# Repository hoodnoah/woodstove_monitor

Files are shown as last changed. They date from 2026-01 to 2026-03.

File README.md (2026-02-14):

# Woodstove Monitor

A Rust-based temperature monitoring system for woodstoves using an Arduino Nano ESP32 and a MAX31855 thermocouple sensor. The device reads temperature data and publishes it to MQTT for remote monitoring.

## Features

- **Temperature Monitoring**: Reads thermocouple data via MAX31855 SPI sensor
- **WiFi Connectivity**: Connects to WiFi networks for remote access
- **MQTT Publishing**: Publishes temperature readings and stove state to an MQTT broker
- **State Machine**: Tracks woodstove burn state based on temperature readings
- **Low Power**: Optimized for minimal resource usage on embedded systems

## Hardware

- Arduino Nano ESP32 (ESP32-S3)
- MAX31855 Thermocouple Amplifier (SPI interface)
- Status LED (GPIO8)
- WiFi antenna

## Project Structure

- `monitor/`: Main ESP32 application (firmware)
  - `main.rs`: Entry point, hardware setup, main loop
  - `mqtt.rs`: MQTT client and publishing logic
  - `wifi.rs`: WiFi connectivity
- `woodstove_lib/`: Shared library with core logic
  - `state_machine.rs`: Stove state tracking
  - `sensor.rs`: Sensor abstractions
  - `temperature.rs`: Temperature value types

## Setup

### Prerequisites

See [SETUP.md](SETUP.md) for detailed platform-specific installation instructions.

**Quick setup:**

1. Install system dependencies (cmake, ninja, LLVM, Python 3.12, etc. - see SETUP.md)
2. Set required environment variables (see SETUP.md)
3. Install ESP tooling:
   ```bash
   just check-deps  # Verify dependencies
   just setup       # Install ESP tools (one-time)
   source ~/export-esp.sh  # Load ESP environment
   ```

### Configuration

Set environment variables for your WiFi and MQTT credentials:

```bash
export WIFI_SSID="your_ssid"
export WIFI_PASSWORD="your_password"
export MQTT_ENDPOINT="mqtt://broker.example.com"
export MQTT_USER="username"
export MQTT_PASS="password"
```

Alternatively, create a `.env` file in the `monitor/` directory.

## Building and Flashing

```bash
# Build release binary
just build

# Flash to device and monitor serial output
just flash

# Monitor only (if device is already flashed)
just monitor

# Clean build artifacts
just clean
```

## Development

```bash
# Test the shared library
just test-lib
```

## Resources

- [esp-rs Book](https://docs.espressif.com/projects/rust/book/)
- [esp-idf-svc Documentation](https://docs.rs/esp-idf-svc/)
- [MAX31855 Datasheet](https://datasheets.maximintegrated.com/en/ds/MAX31855.pdf)

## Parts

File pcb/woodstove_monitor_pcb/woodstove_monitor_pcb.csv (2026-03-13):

Id | Designator | Footprint | Quantity | Designation | Supplier and ref
1 | R4,R5,R6,R1 | R_0805_2012Metric | 4 | 10k
2 | L1 | L_Taiyo-Yuden_NR-50xx | 1 | 4.7uH
3 | C4 | C_0805_2012Metric | 1 | 1uF
4 | U2 | SOIC-8_3.9x4.9mm_P1.27mm | 1 | MAX31855KASA
5 | C12 | C_0805_2012Metric | 1 | 10nF
6 | C3,C7,C1 | C_0805_2012Metric | 3 | 100nF
7 | S1,S2 | SW_PTS526_SMG15_SMTR2_LFS | 2 | PTS526_SMG15_SMTR2_LFS
8 | C9,C11,C8 | C_0805_2012Metric | 3 | 22uF
9 | J3,J1 | TE_284391-2 | 2 | 284391-2
10 | J2 | SAMESKY_UJ20-C-H-G-SMT-P16-TR | 1 | UJ20-C-H-G-SMT-P16-TR
11 | U3 | TSOT-23-6 | 1 | AP63205WU
12 | D2,D1 | D_SOD-323 | 2 | D_Schottky
13 | C2,C6,C10 | C_0805_2012Metric | 3 | 10uF
14 | R3,R2 | R_0805_2012Metric | 2 | 5.1k
15 | U4 | SOT-223-3_TabPin2 | 1 | AZ1117CH2-3.3
16 | U1 | ESP32-C3-WROOM-02 | 1 | ESP32-C3-WROOM-02

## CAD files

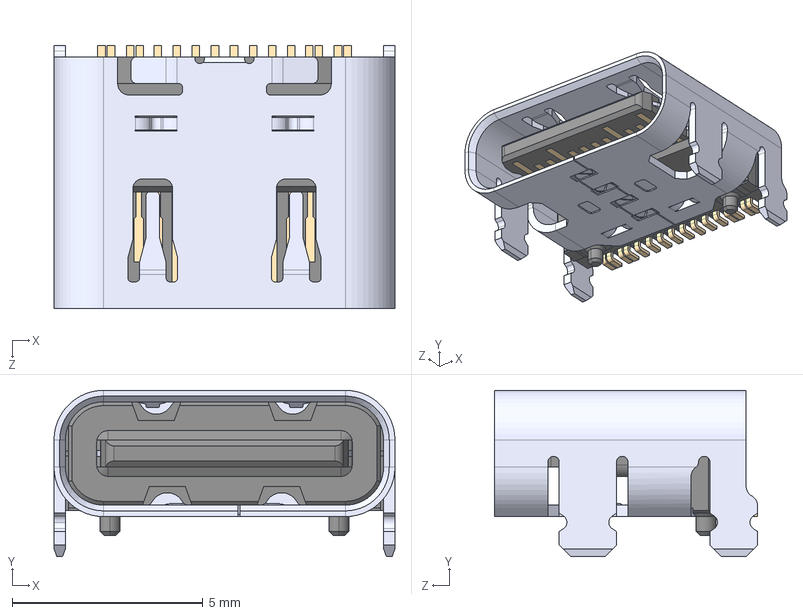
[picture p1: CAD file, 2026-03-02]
pcb/kicad_libraries/DX07S016JA1R1500/DX07S016JA1R1500.step
8.94 x 4.36 x 6.90 mm

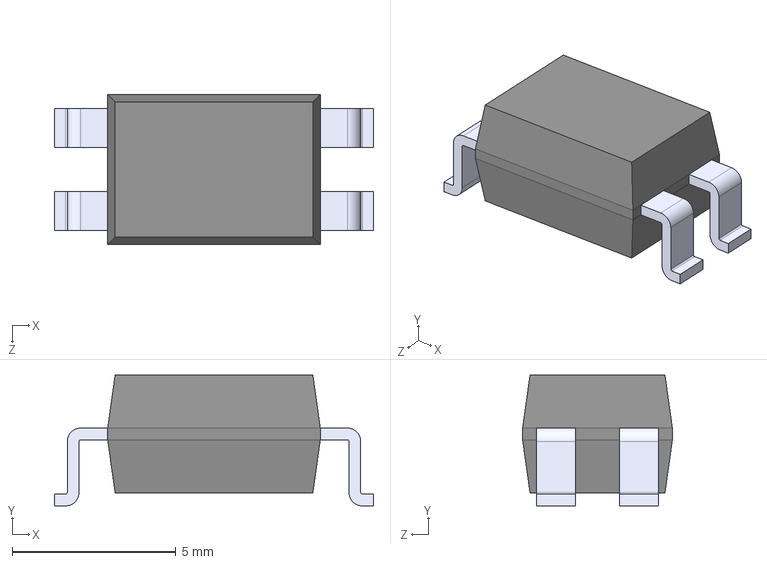
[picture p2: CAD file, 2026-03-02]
pcb/kicad_libraries/PC817X2NIP1B/PC817X2NIP1B.step
9.75 x 4.00 x 4.58 mm

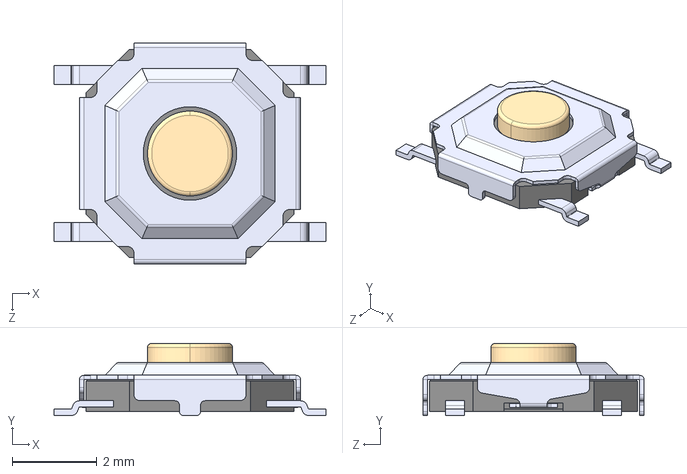
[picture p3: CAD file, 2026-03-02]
pcb/kicad_libraries/PTS526_SMG15_SMTR2_LFS/PTS526_SMG15_SMTR2_LFS.step
6.40 x 1.70 x 5.20 mm

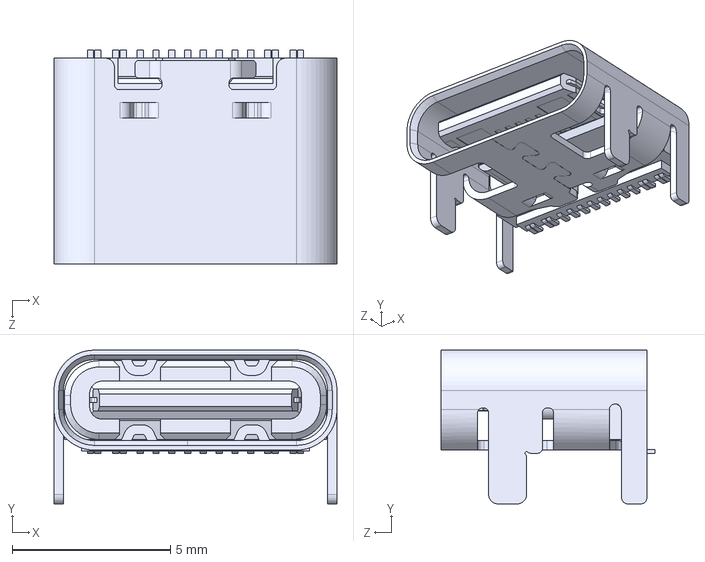
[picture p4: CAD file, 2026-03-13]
pcb/kicad_libraries/UJ20-C-H-G-SMT-P16-TR/UJ20-C-H-G-SMT-P16-TR.step
8.94 x 4.86 x 6.75 mm

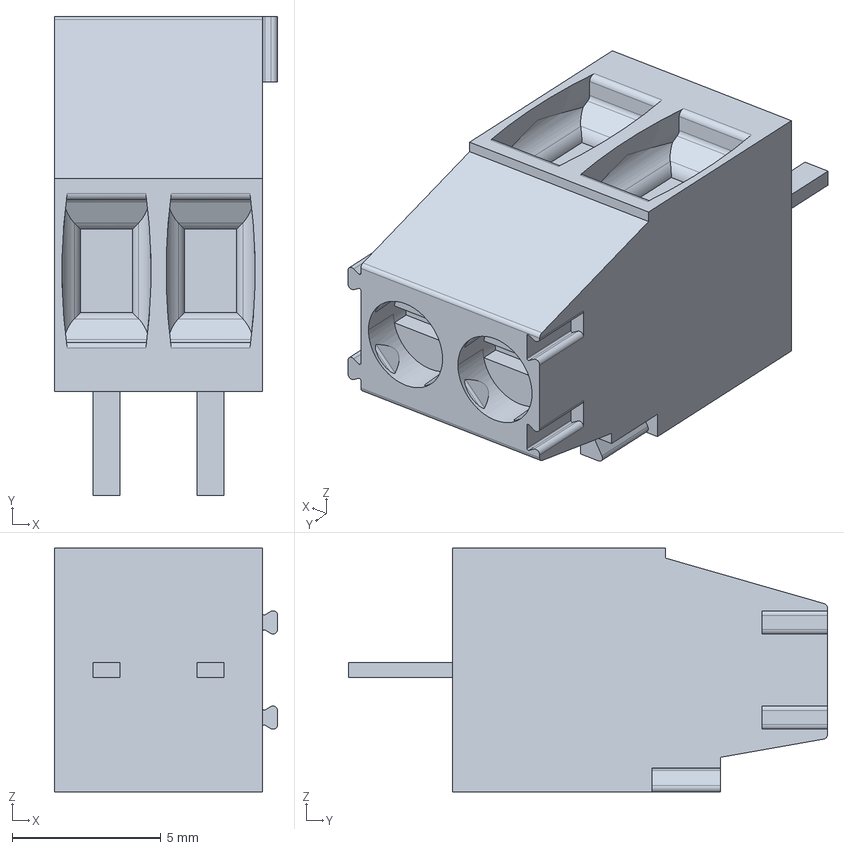
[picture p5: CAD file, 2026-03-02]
pcb/kicad_libraries/284391-2/284391-2.step
7.50 x 16.1 x 8.20 mm

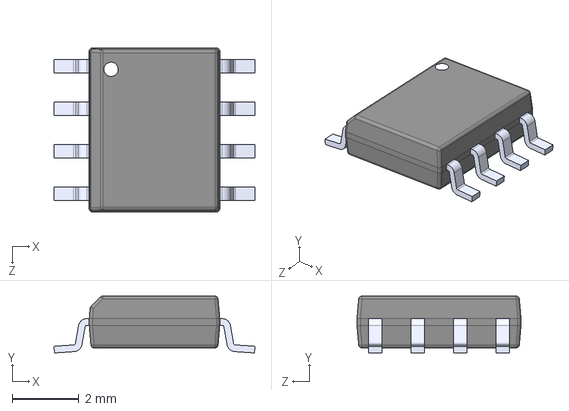
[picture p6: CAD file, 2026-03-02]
pcb/kicad_libraries/LMR14050SDDAR/LMR14050SDDAR.step
6.00 x 1.70 x 4.90 mm

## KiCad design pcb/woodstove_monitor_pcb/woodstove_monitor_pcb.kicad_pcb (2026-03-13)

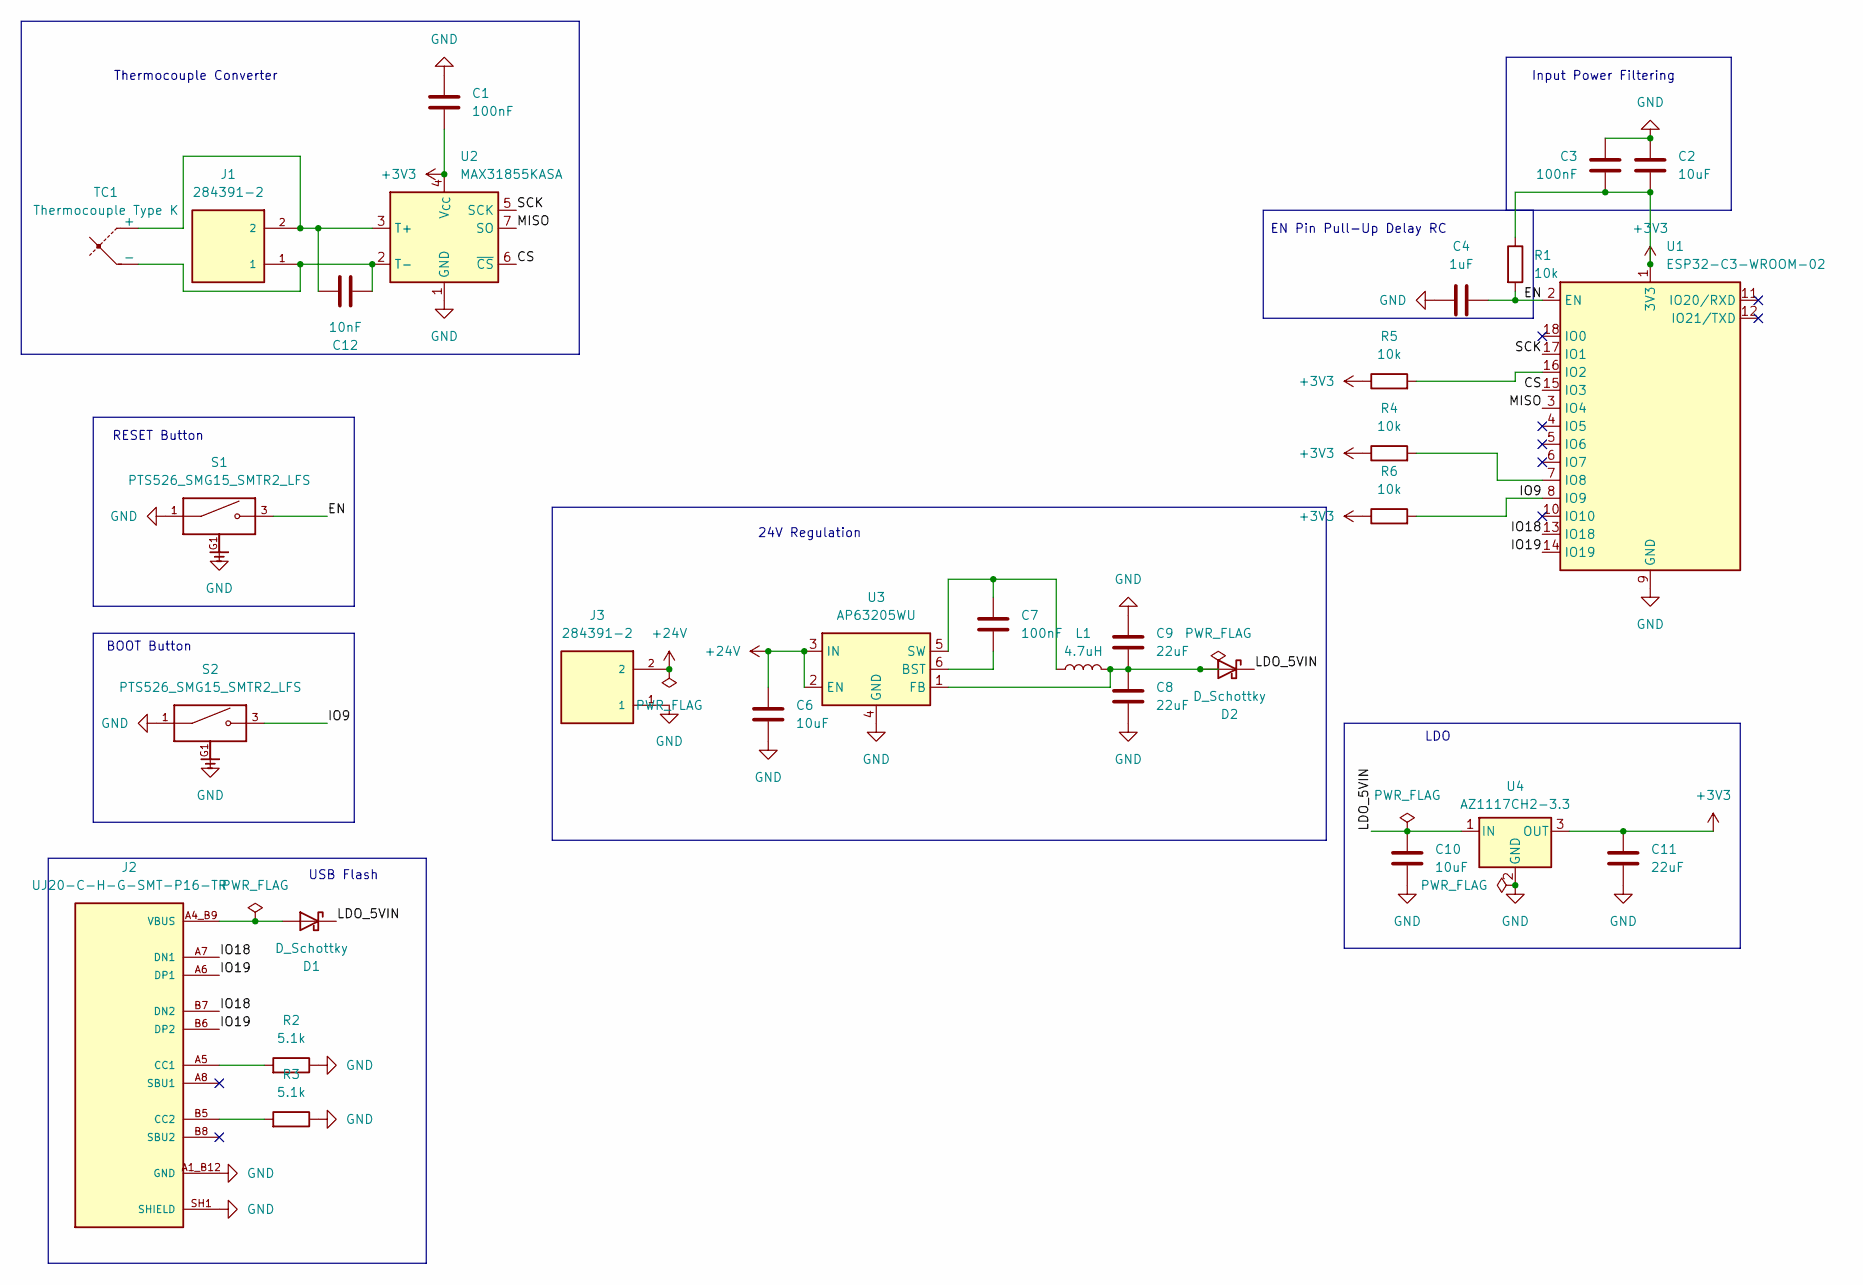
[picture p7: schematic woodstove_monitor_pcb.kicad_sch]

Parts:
C1, C3, C7: 100nF; C_0805_2012Metric; Mouser Part # 80-C0805C104M5RACLR
C2, C6, C10: 10uF; C_0805_2012Metric; Mouser Part # 187-CL21B106KPQNNNE
C4: 1uF; C_0805_2012Metric; Mouser Part # 80-C0805C105K3RACTM
C8, C9, C11: 22uF; C_0805_2012Metric; Mouser Part # 581-KAM21AT70J226MU
C12: 10nF; C_0805_2012Metric; Mouser Part # 80-C0805C103J5RACTM
D1, D2: D_Schottky; D_SOD-323; Mouser Part # 726-BAT60BE6359HTMA1
J1, J3: 284391-2; TE_284391-2; PARTREV C; Mouser Part # 571-284391-2
J2: UJ20-C-H-G-SMT-P16-TR; SAMESKY_UJ20-C-H-G-SMT-P16-TR; PARTREV 1.0; Mouser Part # 179-UJ20CHGSMTP16TR
L1: 4.7uH; L_Taiyo-Yuden_NR-50xx; Mouser Part # 963-NRS5020T4R7MMGJ
R1, R4, R5, R6: 10k; R_0805_2012Metric; Mouser Part # 303-0805S8J0103T5E
R2, R3: 5.1k; R_0805_2012Metric; Mouser Part # 660-SG73S2ATTD512J
S1, S2: PTS526_SMG15_SMTR2_LFS; SW_PTS526_SMG15_SMTR2_LFS; PARTREV 20 Nov 20; Mouser Part # 611-PTS526SMG15SMR2L
TC1: Thermocouple Type K
U1: ESP32-C3-WROOM-02; Mouser Part # 356-ESP32C3WROOM02N4; LCSC Part # C2934560
U2: MAX31855KASA; SOIC-8_3.9x4.9mm_P1.27mm; Mouser Part # 700-MAX31855KASA+
U3: AP63205WU; TSOT-23-6; Mouser Part # 621-AP63205WU-7
U4: AZ1117CH2-3.3; SOT-223-3_TabPin2; Mouser Part # 621-AZ1117CH2-33TRG1

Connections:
+3V3: C1.2, C2.2, C3.2, C11.1, R1.1, R4.1, R5.1, R6.1, U1.1 (3V3), U2.4 (V_{CC}), U4.3 (OUT)
+24V: C6.1, J3.2, U3.2 (EN), U3.3 (IN)
/CS: U1.15 (IO3), U2.6 (~CS)
/EN: C4.1, R1.2, S1.3, S1.4, U1.2 (EN)
/IO9: R6.2, S2.3, S2.4, U1.8 (IO9)
/IO18: J2.A7 (DN1), J2.B7 (DN2), U1.13 (IO18)
/IO19: J2.A6 (DP1), J2.B6 (DP2), U1.14 (IO19)
/LDO_5VIN: C10.1, D1.1 (K), D2.1 (K), U4.1 (IN)
/MISO: U1.3 (IO4), U2.7 (SO)
/SCK: U1.17 (IO1), U2.5 (SCK)
GND: C1.1, C2.1, C3.1, C4.2, C6.2, C8.2, C9.1, C10.2, C11.2, J2.A1_B12 (GND), J2.A12_B1 (GND), J2.SH1 (SHIELD), J2.SH2 (SHIELD), J2.SH3 (SHIELD), J2.SH4 (SHIELD), J3.1, R2.1, R3.1, S1.1, S1.2, S1.G1, S1.G2, S2.1, S2.2, S2.G1, S2.G2, U1.9 (GND), U1.19 (GND), U2.1 (GND), U3.4 (GND), U4.2 (GND)
unnamed: C8.1, C9.2, D2.2 (A), L1.2, U3.1 (FB)
unnamed: J2.A5 (CC1), R2.2
unnamed: J2.B5 (CC2), R3.2
unnamed: R5.2, U1.16 (IO2)
unnamed: R4.2, U1.7 (IO8)
unnamed: C12.2, J1.2, TC1.1 (+), U2.3 (T+)
unnamed: C12.1, J1.1, TC1.2 (-), U2.2 (T-)
unnamed: C7.1, U3.6 (BST)
unnamed: C7.2, L1.1, U3.5 (SW)
VBUS: D1.2 (A), J2.A4_B9 (VBUS), J2.A9_B4 (VBUS)

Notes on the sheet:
Input Power Filtering
BOOT Button
Thermocouple Converter
24V Regulation
USB Flash
RESET Button
EN Pin Pull-Up Delay RC
LDO

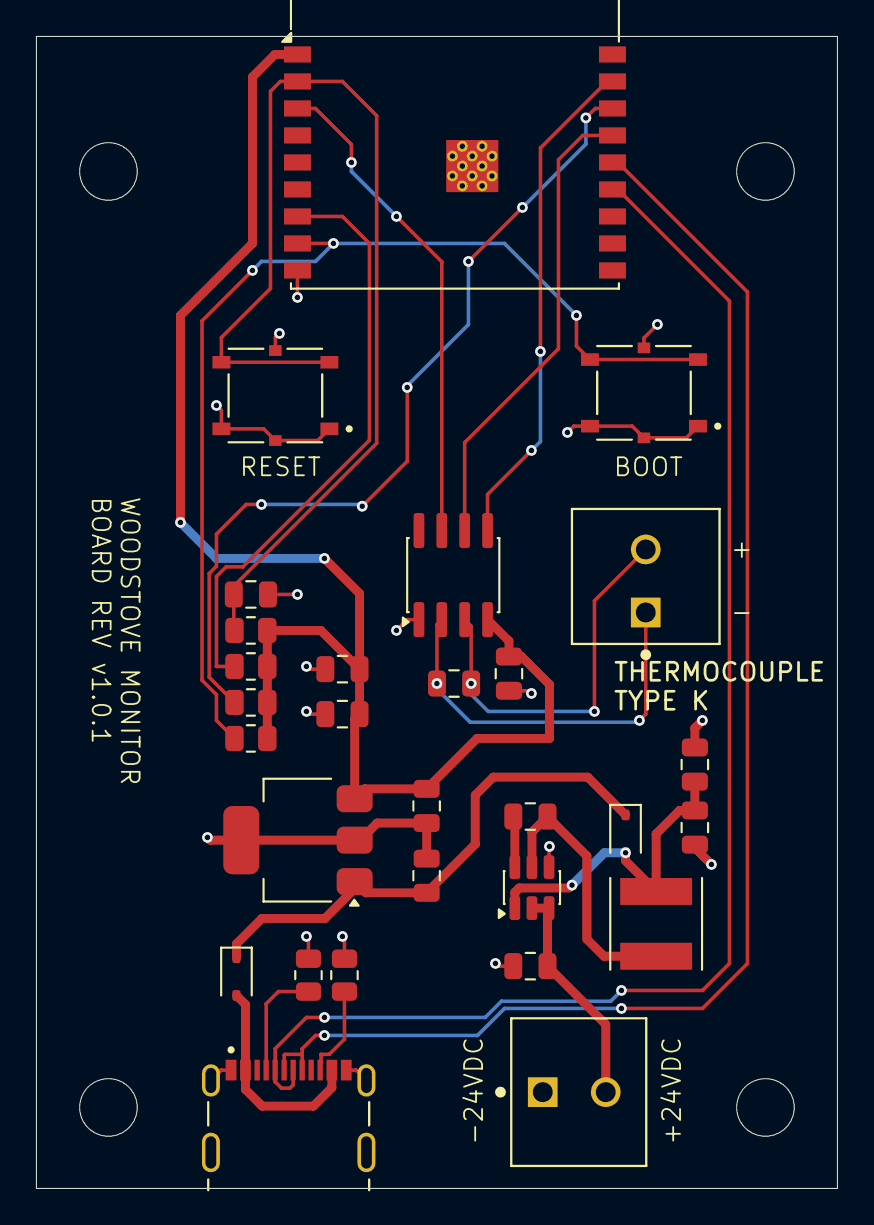
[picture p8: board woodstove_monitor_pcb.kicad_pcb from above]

Board: 2 copper layers, 44.5 x 64.0 mm, 29 parts (0 on the bottom side), 21 nets.

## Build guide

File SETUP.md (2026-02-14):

# Development Environment Setup

This guide explains how to set up your development environment for the ESP32 woodstove monitor project without Nix.

## Prerequisites

This project requires:
- **System build tools**: cmake, ninja, pkg-config, LLVM/clang
- **Rust toolchain**: rustup and cargo
- **Python 3.12+**: For ESP-IDF build system
- **ESP-specific tools**: espup, cargo-espflash

Follow the instructions for your platform below.

---

## macOS (Apple Silicon)

### 1. Install Homebrew (if not already installed)

```bash
/bin/bash -c "$(curl -fsSL https://raw.githubusercontent.com/Homebrew/install/HEAD/install.sh)"
```

### 2. Install System Dependencies

```bash
brew install cmake ninja pkg-config openssl llvm python@3.12 just
```

### 3. Install Rust

If you don't have Rust installed:

```bash
brew install rustup
rustup-init -y
```

**For bash/zsh:**
```bash
source $HOME/.cargo/env
```

**For fish:**
```fish
set -gx PATH $HOME/.cargo/bin $PATH
```

### 4. Set Environment Variables

**For bash/zsh**, add these to your shell profile (~/.zshrc or ~/.bashrc):

```bash
export LIBCLANG_PATH="$(brew --prefix llvm)/lib"
export PKG_CONFIG_PATH="$(brew --prefix openssl)/lib/pkgconfig"
```

**For fish**, add these to ~/.config/fish/config.fish:

```fish
set -gx LIBCLANG_PATH (brew --prefix llvm)/lib
set -gx PKG_CONFIG_PATH (brew --prefix openssl)/lib/pkgconfig
```

Then reload your shell:

```bash
source ~/.zshrc  # or source ~/.bashrc
```

```fish
source ~/.config/fish/config.fish
```

### 5. Install ESP Tooling

```bash
cargo install espup cargo-espflash espflash
espup install --targets "esp32s3"
```

### 6. Load ESP Environment

**For bash/zsh:**
```bash
source ~/export-esp.sh
```

Add this to your shell profile for automatic loading:

```bash
echo 'source ~/export-esp.sh' >> ~/.zshrc
```

**For fish:**
```fish
source ~/export-esp.sh
```

Add this to ~/.config/fish/config.fish for automatic loading:

```fish
source ~/export-esp.sh
```

### 7. Verify Installation

```bash
cd /path/to/woodstove_monitor
just check-deps
```

---

## Linux (x86_64 - Debian/Ubuntu)

### 1. Install System Dependencies

```bash
sudo apt update
sudo apt install -y \
    cmake ninja-build pkg-config libssl-dev \
    llvm libclang-dev clang \
    python3 python3-pip python3-venv \
    git curl build-essential \
    udev libusb-1.0-0 libudev-dev
```

### 2. Install just (command runner)

Ubuntu/Debian repositories may have an outdated version. Install from cargo:

```bash
# Skip this if apt has a recent version
cargo install just
```

Or use the prebuilt binary:

```bash
curl --proto '=https' --tlsv1.2 -sSf https://just.systems/install.sh | bash -s -- --to ~/bin
```

### 3. Install Rust

If you don't have Rust installed:

```bash
curl --proto '=https' --tlsv1.2 -sSf https://sh.rustup.rs | sh -s -- -y
```

**For bash/zsh:**
```bash
source $HOME/.cargo/env
```

**For fish:**
```fish
set -gx PATH $HOME/.cargo/bin $PATH
```

### 4. Set Environment Variables

Find your LLVM version:

```bash
ls /usr/lib/ | grep llvm
```

**For bash/zsh**, add to your shell profile (~/.bashrc or ~/.zshrc):

```bash
# Replace '14' with your LLVM version
export LIBCLANG_PATH=/usr/lib/llvm-14/lib
```

**For fish**, add to ~/.config/fish/config.fish:

```fish
# Replace '14' with your LLVM version
set -gx LIBCLANG_PATH /usr/lib/llvm-14/lib
```

Reload your shell:

```bash
source ~/.bashrc
```

```fish
source ~/.config/fish/config.fish
```

### 5. Configure USB Permissions for ESP32

```bash
# Add yourself to dialout group
sudo usermod -a -G dialout $USER

# Create udev rule for ESP32
sudo tee /etc/udev/rules.d/99-esp32.rules > /dev/null <<EOF
SUBSYSTEMS=="usb", ATTRS{idVendor}=="303a", ATTRS{idProduct}=="1001", MODE="0666"
EOF

# Reload udev rules
sudo udevadm control --reload-rules
```

**Important**: Log out and log back in for group membership to take effect.

### 6. Install ESP Tooling

```bash
cargo install espup cargo-espflash espflash
espup install --targets "esp32s3"
```

### 7. Load ESP Environment

**For bash/zsh:**
```bash
source ~/export-esp.sh
```

Add to your shell profile for automatic loading:

```bash
echo 'source ~/export-esp.sh' >> ~/.bashrc
```

**For fish:**
```fish
source ~/export-esp.sh
```

Add to ~/.config/fish/config.fish for automatic loading:

```fish
source ~/export-esp.sh
```

### 8. Verify Installation

```bash
cd /path/to/woodstove_monitor
just check-deps
```

---

## Using the Project

### Environment Setup (Each Session)

Instead of nix develop, source the environment helper:

**For bash/zsh:**
```bash
cd woodstove_monitor
source env.sh
```

**For fish:**
```fish
cd woodstove_monitor
source env.sh
```

This automatically:
- Sets LIBCLANG_PATH for your platform
- Sources ESP toolchain (~/export-esp.sh)
- Loads WiFi/MQTT credentials from monitor/.env if present

### Building and Flashing

```bash
# Check dependencies
just check-deps

# Build release binary
just build

# Flash to device and monitor
just flash

# Monitor only
just monitor
```

### Configuration

Create monitor/.env with your WiFi and MQTT credentials:

```bash
WIFI_SSID=your_network
WIFI_PASSWORD=your_password
MQTT_ENDPOINT=mqtt://broker.example.com
MQTT_USER=mqtt_user
MQTT_PASS=mqtt_password
```

---

## Troubleshooting

### "libclang not found" or "bindgen failed"

**Symptom**: Build fails with errors about libclang or bindgen.

**Solution**:
- Ensure LIBCLANG_PATH is set correctly
- macOS: `export LIBCLANG_PATH="$(brew --prefix llvm)/lib"`
- Linux: `export LIBCLANG_PATH=/usr/lib/llvm-<version>/lib`

### "espflash: command not found"

**Symptom**: Can't flash the ESP32 device.

**Solution**:
- Ensure ~/.cargo/bin is in your PATH
- Run: `cargo install espflash cargo-espflash`

### "Permission denied" when flashing (Linux)

**Symptom**: Can't access /dev/ttyUSB0 or /dev/ttyACM0.

**Solution**:
- Add yourself to dialout group: `sudo usermod -a -G dialout $USER`
- Log out and log back in
- Verify: `groups` (should include "dialout")

### ESP environment not loading

**Symptom**: ~/export-esp.sh not found.

**Solution**:
- Run `espup install --targets "esp32s3"`
- This creates ~/export-esp.sh automatically

### First build is very slow

**Expected behavior**: The first build downloads and compiles ESP-IDF (10-15 minutes). Subsequent builds are fast (<1 minute for incremental changes).

---

## Differences from Nix Setup

| Aspect | Nix (Old) | Direct Install (New) |
|---|---|---|
| Environment activation | nix develop (automatic with direnv) | source env.sh |
| Dependency installation | Automatic | Manual per platform |
| Reproducibility | Exact versions locked | System package versions |
| Setup time | ~5 minutes (first time) | ~10-15 minutes |
| Updates | nix flake update | brew upgrade / apt upgrade |

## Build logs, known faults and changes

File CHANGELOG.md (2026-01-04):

# Changelog

All notable changes to this project will be documented in this file.

The format is based on [Keep a Changelog](https://keepachangelog.com/en/1.1.0/),
and this project adheres to [Semantic Versioning](https://semver.org/spec/v2.0.0.html).

## [Unreleased]

### Changed

- Fix state transition bug where overheat skips from overheat to coaling, and therefore doesn't trigger the state change 
  to coaling, on which the reload notification relies.

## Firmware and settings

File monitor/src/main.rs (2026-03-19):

mod config_store;
mod mqtt;
mod wifi;

use esp_idf_svc::{
    hal::{
        delay::FreeRtos,
        gpio::*,
        peripherals::Peripherals,
        spi::{
            config::{Config, DriverConfig, Mode, Phase},
            *,
        },
        units::*,
    },
    nvs::EspDefaultNvsPartition,
    sys::EspError,
};
use max31855::{Max31855, Unit};
use mqtt::WoodstoveMQTT;
use woodstove_lib::{StoveStateMachine, Temperature};

const WIFI_SSID: &str = env!("WIFI_SSID");
const WIFI_PASSWORD: &str = env!("WIFI_PASSWORD");
const MQTT_ENDPOINT: &str = env!("MQTT_ENDPOINT");
const MQTT_USER: &str = env!("MQTT_USER");
const MQTT_PASS: &str = env!("MQTT_PASS");

const LOOP_DELAY_MS: u32 = 10_000;
const WIFI_CHECK_INTERVAL: u32 = 5; // every 5 loops, 50 seconds

fn log_publish_result(name: &str, result: Result<u32, EspError>) {
    match result {
        Ok(_) => log::info!("Published {}", name),
        Err(e) => log::warn!("Failed to publish {}: {:?}", name, e),
    }
}

fn main() -> anyhow::Result<()> {
    // It is necessary to call this function once. Otherwise, some patches to the runtime
    // implemented by esp-idf-sys might not link properly. See https://github.com/esp-rs/esp-idf-template/issues/71
    esp_idf_svc::sys::link_patches();

    // Bind the log crate to the ESP Logging facilities
    esp_idf_svc::log::EspLogger::initialize_default();

    // setup SPI for thermocouple reads
    let peripherals = Peripherals::take().unwrap();

    let freq: Hertz = 4.MHz().into();
    let mode = Mode {
        polarity: config::Polarity::IdleLow,
        phase: Phase::CaptureOnFirstTransition,
    };

    let bus_config = DriverConfig::new();

    let config = Config::new().baudrate(freq).data_mode(mode);

    let mut spi = SpiDeviceDriver::new_single(
        peripherals.spi2,
        peripherals.pins.gpio1,       // CLK/SCK (GPIO1)
        peripherals.pins.gpio21,      // (dummy, just put one randomly)
        Some(peripherals.pins.gpio4), // DO (GPIO4)
        Option::<AnyIOPin>::None,     // handled elsewhere, CS
        &bus_config,
        &config,
    )
    .unwrap();

    let mut cs = PinDriver::output(peripherals.pins.gpio3).unwrap(); // CS (GPIO3)

    log::info!("SPI and CS configured successfully!");

    // Take the NVS partition once. It's Arc-backed so we can clone it for WiFi.
    let nvs = EspDefaultNvsPartition::take()?;

    // Load persisted config (falls back to defaults on first boot or parse error)
    let initial_config = config_store::load_from_nvs(&nvs);

    // Setup wifi (needs the NVS partition for calibration data)
    let mut wifi_handler =
        wifi::WifiHandler::new(peripherals.modem, WIFI_SSID, WIFI_PASSWORD, nvs.clone())?;
    wifi_handler.connect()?;
    log::info!("wifi connected");

    // Setup mqtt
    let mut mqtt_handler =
        WoodstoveMQTT::new("woodstove_monitor", MQTT_ENDPOINT, MQTT_USER, MQTT_PASS)?;

    // Publish the active config on boot so the broker reflects current thresholds
    log_publish_result("config", mqtt_handler.publish_config(&initial_config));

    // Setup the state machine with the loaded (or default) config
    let mut stove_state_machine = StoveStateMachine::with_config(initial_config);

    let mut wifi_connected = true;
    let mut loops_since_wifi_check = 0u32;

    loop {
        if loops_since_wifi_check >= WIFI_CHECK_INTERVAL {
            match wifi_handler.ensure_connected() {
                Ok(_) => {
                    if !wifi_connected {
                        log::info!("WiFi connection restored");
                    }
                    wifi_connected = true;
                }
                Err(e) => {
                    log::error!("WiFi check failed: {:?}", e);
                    wifi_connected = false;
                }
            }
            loops_since_wifi_check = 0;
        }

        // Subscribe after MQTT connects or reconnects (safe to call every iteration)
        mqtt_handler.subscribe_if_needed();

        // Check for a pending config update received via MQTT
        if let Some(json) = mqtt_handler.take_config_update() {
            match config_store::apply_update(stove_state_machine.config(), &json) {
                Ok(new_config) => {
                    config_store::save_to_nvs(&nvs, &new_config);
                    log_publish_result("config", mqtt_handler.publish_config(&new_config));
                    stove_state_machine.update_config(new_config);
                    log::info!("Config updated and persisted");
                }
                Err(e) => log::warn!("Invalid config update payload: {e:?}"),
            }
        }

        match Max31855::read_thermocouple(&mut spi, &mut cs, Unit::Celsius) {
            Ok(temp_c) => {
                let temp = Temperature::from_celsius(temp_c);

                // publish temperature
                log_publish_result("temperature", mqtt_handler.publish_temperature(&temp));

                // update state machine
                let state_changed = stove_state_machine.update(temp);

                let state_string = stove_state_machine.current_state().to_string();

                if state_changed {
                    log::info!("State changed to: {}", state_string);
                }

                log_publish_result(
                    "state",
                    mqtt_handler.publish_state(stove_state_machine.current_state()),
                );

                // publish time in state every 6th loop
                log_publish_result(
                    "time in state",
                    mqtt_handler.publish_time_in_state(stove_state_machine.time_in_state()),
                );

                // publish status
                log_publish_result("status", mqtt_handler.publish_status());
            }
            Err(e) => {
                let error_msg = format!("Sensor error: {:?}", e);

                if let Err(mqtt_err) = mqtt_handler.publish_error(error_msg.clone()) {
                    log::warn!("Failed to publish sensor error: {:?}", mqtt_err);
                }

                log::error!("Sensor error: {:?}", e);
            }
        }

        loops_since_wifi_check += 1;
        FreeRtos::delay_ms(LOOP_DELAY_MS);
    }
}

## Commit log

2025-12-15 implement EMA for calculating rate of change of temperature
2025-12-24 add dependency on MAX31855 crate for thermocouple driver
2025-12-25 implement utility types over temperature, rates of change, temperature deltas to prevent unit commingling; reimplement unit tests
    formalize unit types, refactor state_machine, some tests to make use of new types
    checkpoint
2025-12-26 rudimentary implementation of sensor functionality
2025-12-26 setup wifi, switch to arduino nano esp32 since wifi is broken on esp32c3
    checkpoint before switching to ardunio esp32
    setup wifi, switch to arduino nano esp32 since wifi is broken on esp32c3
    [main.rs]
2025-12-26 working mqtt
    [partitions.csv]
2025-12-28 implement Display trait for BurnState enum
    [main.rs]
2026-01-25 fix crash when mqtt broker is down, reduce boilerplate
    [main.rs]
2026-01-25 cargo fix to remove unused imports
    [main.rs]
2026-02-14 implement wifi reconnection logic following power outage exposing no reconnection logic
2026-03-02 v1 schematic
    [284391-2.step, DX07S016JA1R1500.step, LMR14050SDDAR.step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]
2026-03-13 update part no. for LDO; MUST BE H2 version, not H1
    [UJ20-C-H-G-SMT-P16-TR.step, woodstove_monitor_pcb.csv, woodstove_monitor_pcb.kicad_pcb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]
2026-03-19 update dummy pin, build config
